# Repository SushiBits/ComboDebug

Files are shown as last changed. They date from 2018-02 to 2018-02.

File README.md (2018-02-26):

# ComboDebug ARM JTAG Adapter

ComboDebug is a companion adapter for [DAP42][DAP42] debug probe, as well as
standard ARM debuggers with 2.54mm 20-pin interface like [J-Link][JLINK] and
[ST-Link][SLINK].

## Introduction

DAP42 is a CMSIS-DAP compatible USB JTAG debug adapter for ARM Cortex-A and
Cortex-M processors, based on the [STM32F042K6][42K] microcontroller.

This adapter provides a 1.27mm 10-pin modified Cortex Debug Connector with two
of the original ground lines replaced with a serial port.

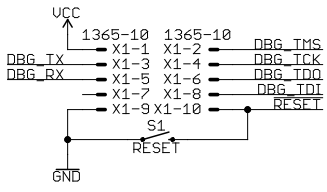
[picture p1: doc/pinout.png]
Pinout diagram


The serial port can be handled through the DAP42 host interface, or through an
onboard USB to Serial adapter.

It also provides an external target reset button, and an offline programming
trigger button for [DAP42][DAP42]

## License and contact

This is open source hardware under [3-clause BSD license][3BSDL].

[JLINK]: https://www.segger.com/products/debug-probes/j-link/
[SLINK]: http://www.st.com/en/development-tools/st-link-v2.html
[42K]:   http://www.st.com/en/microcontrollers/stm32f042k6.html
[DAP42]: https://github.com/SushiBits/DAP42
[3BSDL]: LICENSE.md

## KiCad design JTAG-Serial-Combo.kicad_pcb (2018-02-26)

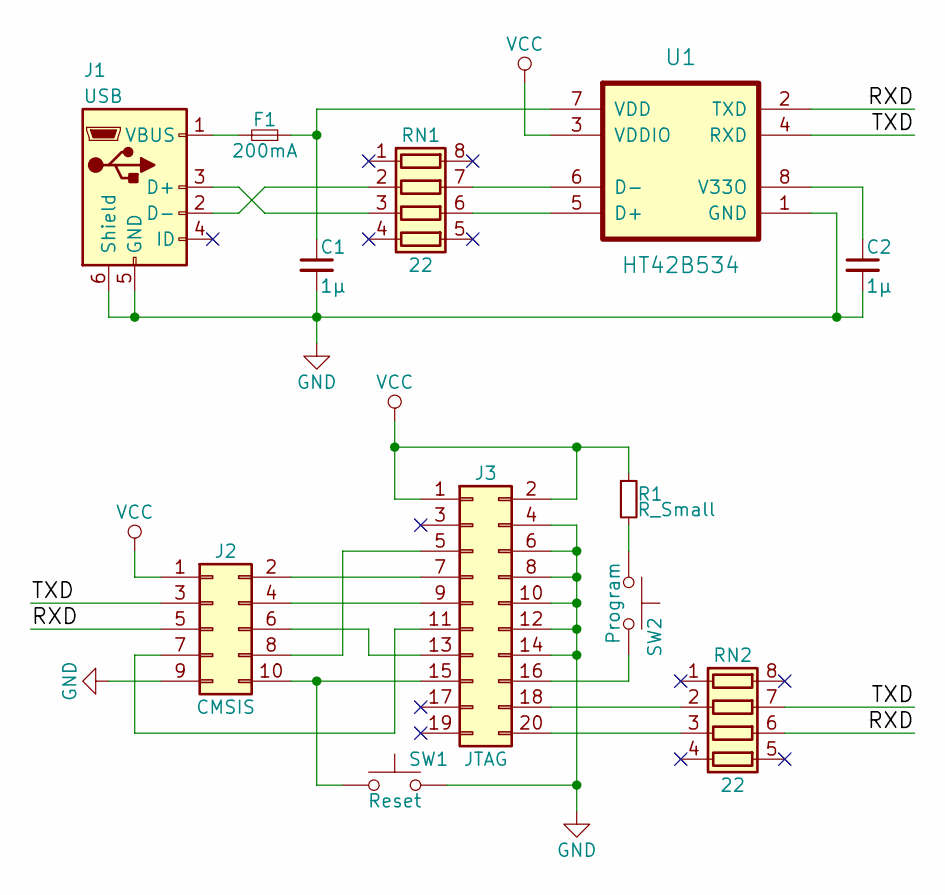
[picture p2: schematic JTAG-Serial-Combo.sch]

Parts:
C1, C2: 1µ; C_0603_HandSoldering
F1: 200mA; R_0805_HandSoldering
J1: USB; USB_Micro-B
J2: CMSIS; Pin_Header_Straight_2x05_Pitch1.27mm_SMD
J3: JTAG; Socket_Strip_Straight_2x10_Pitch2.54mm
R1: R_Small; R_0603_HandSoldering
RN1, RN2: 22; R_Array_Concave_4x0603
SW1: Reset; SW_SPST_FSMSM
SW2: Program; SW_SPST_FSMSM
U1: HT42B534; SOIC-8_3.9x4.9mm_Pitch1.27mm

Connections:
/RXD: J2.5, RN2.6 (R3.2), U1.2 (TXD)
/TXD: J2.3, RN2.7 (R2.2), U1.4 (RXD)
GND: C1.2, C2.2, J1.5 (GND), J1.6 (Shield), J2.9, J3.4, J3.6, J3.8, J3.10, J3.12, J3.14, SW1.2, U1.1 (GND)
unnamed: C1.1, F1.1, U1.7 (VDD)
unnamed: C2.1, U1.8 (V33O)
unnamed: F1.2, J1.1 (VBUS)
unnamed: J1.2 (D-), RN1.2 (R2.1)
unnamed: J1.3 (D+), RN1.3 (R3.1)
unnamed: J2.2, J3.7
unnamed: J2.4, J3.9
unnamed: J2.6, J3.13
unnamed: J2.7, J3.11
unnamed: J2.8, J3.5
unnamed: J2.10, J3.15, SW1.1
unnamed: J3.16, SW2.2
unnamed: J3.18, RN2.2 (R2.1)
unnamed: J3.20, RN2.3 (R3.1)
unnamed: R1.2, SW2.1
unnamed: RN1.6 (R3.2), U1.5 (D+)
unnamed: RN1.7 (R2.2), U1.6 (D-)
VCC: J2.1, J3.1, J3.2, R1.1, U1.3 (VDDIO)

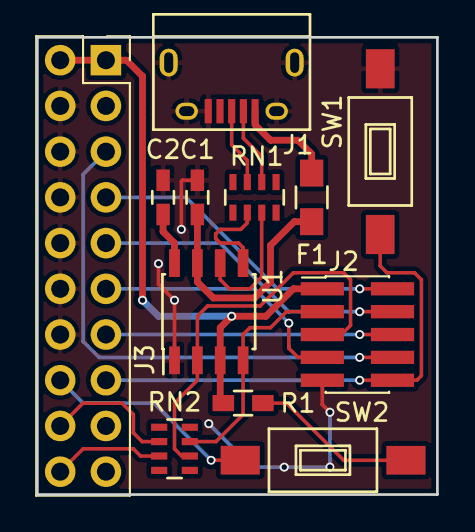
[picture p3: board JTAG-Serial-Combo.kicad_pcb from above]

Board: 2 copper layers, 22.2 x 25.4 mm, 12 parts (0 on the bottom side), 21 nets.
